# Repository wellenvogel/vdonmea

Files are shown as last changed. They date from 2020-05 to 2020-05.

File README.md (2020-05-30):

NMEA 0183 für VDO Windmesser
============================

Basierend auf einem Beitrag im [Segeln Forum](https://www.segeln-forum.de/board194-boot-technik/board35-elektrik-und-elektronik/board195-open-boat-projects-org/75527-reparaturhilfe-f%C3%BCr-vdo-windmessgeber/)
habe ich mit einem Arduino Nano und 8 Widerständen einen einfachen NMEA Adapter gebaut, der die Windrichtungsdaten und die Wind-Geschwindigkeit in einen MWV Datensatz übersetzt.
Der Arduino code enhtält einen einfachen Programmier-Mode um einen Abgleich auf die vorhandene Hardware zu machen.
Es müssen die Anschlüsse:
Farbe    |    Bedeutung
---------|--------------
grau     | Referenz-Spannung
weiss    | Geschwindigkeits-Puls
gelb     | "sinus"
grün     | "cosinus"
blau     | Masse

verbunden werden. 

Die Spannungswerte der 3 analogen Signale (grau,gelb,grün) werden mit Spannungsteilern auf auf einen Bereich von 0...ca. 3V umgesetzt, um sicher im Arbeitsbereich der A/D Wandler zu bleiben. Grau wird dabei als Referenz genutzt, damit ist die Versorgungsspannung des Arduino unkritisch.

Die Werte der Widerstände können ggf. im Sketch angepasst werden.

Wichtig ist es, vor der Nutzung eine Kalibrierung vorzunehmen - dazu nach den upload des sketch mit der seriellen Konsole verbinden (Standard: 19200 baud) und durch Eingabe von __xxprog__ in den Programmiermodus schalten.
Danach __minmax__ zum Start des Abgleichs der Minimal- und Maximalwerte angeben. Jetzt die Windfahne mehrfach langsam drehen bis sich die fortlaufend angezeigten Min- und Max-Werte nicht mehr ändern.
Jetzt die Fahne auf 0° stellen und mit dem Befehl __zero__ den 0-Offset einstellen.

Danach __save__ zum Speichern der Werte im Eeprom und __cancel__ zum Verlassen des Programmiermodus.

Es können noch weitere Werte eingestellt werden:

Kommando      |   Wert
--------------|---------
__interval__  | Aussende-Intervall in ms
__knotsperhz__| Knoten pro Hertz zum Anpassen der Geschwindigkeitsanzeige
__minpulse__  | minimale Zahle der Windimpulse, wenn in einem Intervall weniger Impulse vorhanden sind, wird über mehrere Intervalle gemittelt
__averagefactor__| Factor für eine Mittelwertbildung des Winkels (<1)
__talker__ | die genutzte talker id für den NMEA output

Im Programmier-Modus kann über __help__ eine Hilfe ausgegeben werden.

Falls eine "richtige" NMEA0183 Verbindung aufgebaut werden soll, müssen an den Arduino noch Pegelwandler angeschlossen werden (für die serielle Schnittstelle). Ausserdem benötigt er eine Stromversorgung.
Wenn aber ohnehin ein Anschluss per USB erfolgen soll (z.B. an einen Raspberry Pi) kann das direkt über die USB Schnittstelle des Arduino erfolgen.

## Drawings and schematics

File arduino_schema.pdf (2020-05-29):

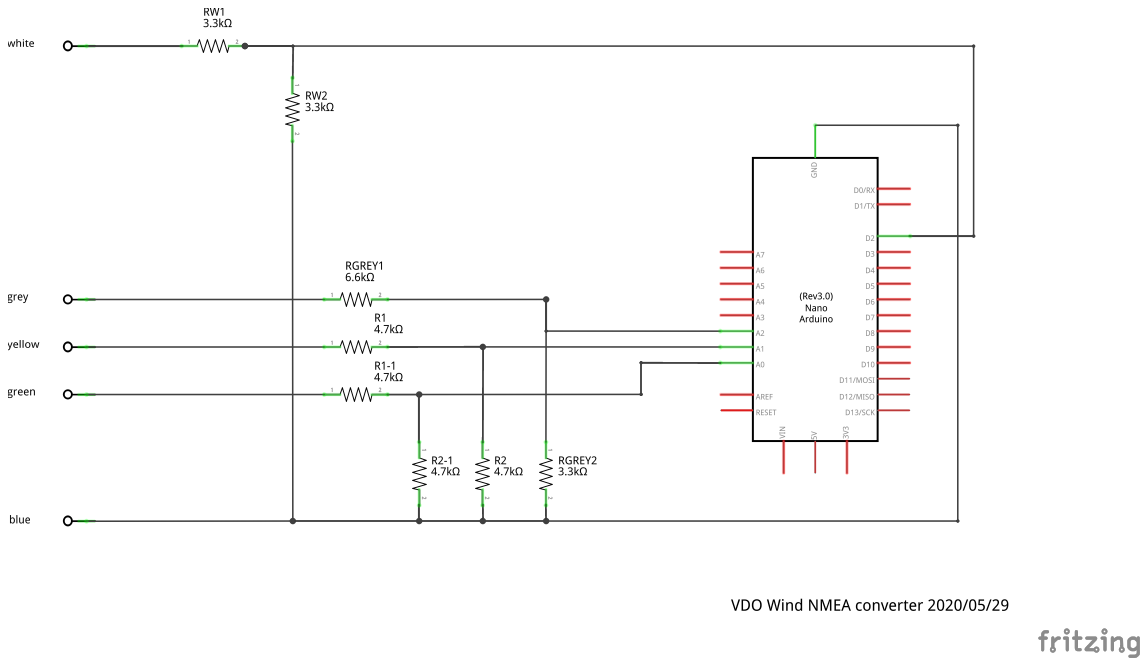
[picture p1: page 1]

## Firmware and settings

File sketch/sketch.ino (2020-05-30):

/**
 * sketch to read the wind data from a VDO
 * (C) Andreas Vogel, www.wellenvogel.de
 * License: MIT
 */
#include "Settings.h"
#define FH(x) (const __FlashStringHelper *)(x)
#define PM(n,value) static const PROGMEM char n[]=value


/*#define DEBUG*/
#define IPIN 2
//pins - grey: vref (~8V), green,yellow: direction
#define GREY_PIN A2
#define YELLOW_PIN A1
#define GREEN_PIN  A0
//NMEA output speed
#define SPEED 19200


//resistors used to divide the input voltage
//we assume similar ones for green and yellow
//the division should consider a low power on the arduino
//so in this set up input 6v will give us 3V at the arduino pins
#define R1 4.7
#define R2 4.7

//grey has different resistors to bringe the voltage more down
//with this set up we lower it to 1/3 - app. 2.75V for our voltage
#define RGREY1 6.6
#define RGREY2 3.3

//the measured reference voltage (grey line) - this is used as the reference for our voltages
#define VREF 8.23
/**
 * computation of angles
 * we start with some min/max values - but the will adapt
 * yellow is sin, green is cos
 * from the voltages we compute an angle and afterwards we average
 */



//values for min max when going to prog
#define PROG_MAX 3.1
#define PROG_MIN 3.0

const char DELIMITER[] = " ";
volatile unsigned long icount;
unsigned long lastCount;
unsigned long ts;
unsigned long lastOutput;
unsigned long lastInput;
char nmeabuf[100];

class TimeCount{
  public:
  unsigned long ts;
  unsigned long count;
  TimeCount(unsigned long count, unsigned long ts){
    this->count=0;
    this->ts=ts;
  }
  TimeCount(){
    count=0;
    ts=0;
  }
};

//how many counters we store
#define MAXCOUNT 10
TimeCount counterValues[MAXCOUNT];
int currentCounterValue;
int maxCounterValue;

#define MAXLINE 100
char receive[MAXLINE+1];
int receivedints=0;

void isr(){
  icount++;
}

#define ANALOG_RESOLUTION_BITS 10

float analogResolution = 1 << ANALOG_RESOLUTION_BITS;
float factor=(R1+R2)/R2/analogResolution;
float factorGrey=(RGREY1+RGREY2)/RGREY2/analogResolution;

float currentAngle;
//ignore voltages lower then this
#define MIN_MEASURE 0.5

//balance for averageing between cos and sin
//this is the weight if the value is at 0, if the value ist at 1 the weight is 1
//this honors that values around 0 are more precise that at 1
#define AVMAX 10

//the amplitude of sin/cos
float amp=1;

#define PROG_DELAY      5000
#define PROG_INTERVAL   1000
//programming mode
bool progMode;
bool progOutput;
bool minMaxMode;


Settings settings;



float hzToKn(float hz){
  return hz*settings.currentValues.hztokn;
}




int toHex(int c){
  c=c & 0xf;
  if (c <= 9) return '0'+c;
  else return 'A'+c-10;
}

const char * formatNmea(float windKn,float angle){
  char speeds[10];
  char angles[10];
  dtostrf(windKn,1,1,speeds);
  dtostrf(angle,1,1,angles);
  sprintf(nmeabuf,"$%c%cMWV,%s,R,%s,N,A",
    settings.currentValues.talker[0],
    settings.currentValues.talker[1],
    angles,speeds);
  int crc=0;
  for (int i=1;i<strlen(nmeabuf);i++){
    crc = crc ^ nmeabuf[i];
  }
  sprintf(nmeabuf+strlen(nmeabuf),"*%c%c",toHex(crc>>4),toHex(crc));
  return nmeabuf;
}


void computeAmplitude(){
  amp=(settings.currentValues.maxValue-settings.currentValues.minValue)/2;
}


float handleMinMax(float v){
  bool hasChanged=false;
  if (v > settings.currentValues.maxValue){
    if (! minMaxMode ){
      v=settings.currentValues.maxValue;
    }
    else{
      settings.currentValues.maxValue=v;
      hasChanged=true;
    }
  }
  if (v < settings.currentValues.minValue){
    if (! minMaxMode || v < MIN_MEASURE){
      v=settings.currentValues.minValue;
    }
    else{
      settings.currentValues.minValue=v;
      hasChanged=true;
    }
  }
  if (hasChanged){
    computeAmplitude();
  }
  return v;
}


float getWeight(float v){
  if (v < 0) v = -v;
  v= (1-v) * (AVMAX-1) +1;
  return v;
}
#define MAXVAL 0.99999
float computeAngle(bool doAverage=true){
  float grey=(float)analogRead(GREY_PIN)*factorGrey;
  float windAngle=0;
  float scale=1.0;
  if (grey < 0.01){
    Serial.print("grey to small");
    Serial.println();
    return 0.0;
  }
  else{
    scale=VREF/grey;
  }
  int green=analogRead(GREEN_PIN);
  float vgreen=factor*green*scale;
  int yellow=analogRead(YELLOW_PIN);
  float vyellow=factor*yellow*scale;

  float vyellowC=handleMinMax(vyellow);
  float vgreenC=handleMinMax(vgreen);
  float vgscaled=(vgreenC-settings.currentValues.minValue)/amp-1;
  if (vgscaled >= 1) vgscaled=MAXVAL;
  if (vgscaled <= -1) vgscaled=-MAXVAL;
  float vyscaled=(vyellowC-settings.currentValues.minValue)/amp-1;
  if (vyscaled >= 1) vyscaled=MAXVAL;
  if (vyscaled <= -1) vyscaled=-MAXVAL;

  float weighty=getWeight(vyscaled);
  float weightg=getWeight(vgscaled);
  //now the quadrants 
  //asin from -90...90
  //acos from 0...180
  float wsin=180/PI*asin(vyscaled);
  float wcos=180/PI*acos(vgscaled);
  //1. 0...90 wsin ok, wcos ok (both 0...90)
  if (vyscaled >=0 && vgscaled >=0){
    if (wcos >= 90) wcos=180-wcos;
  } else
  //2. 90...180 wcos ok, wsin correct 
  if (vyscaled >=0 && vgscaled <=0) {
    if (wsin < 90) wsin=180.0-wsin;
  } else
  //3. -180...-90
  if (vyscaled < 0 && vgscaled < 0){
     wsin=-180-wsin;
     wcos=-wcos;
  }else
  //4. -90...0 wsin ok, wcos correct
  if (vyscaled <0 && vgscaled >=0){
    wcos=-wcos;
  }
  float diffraw=wsin-wcos;
  if ((wsin < -170 || wsin > 170) && (wcos < -170 || wcos > 170) && (diffraw < -180 || diffraw > 180)){
    //sin is the better one in this area
    wcos=-wcos;
  }
  float wfinal=(weighty *wsin+ weightg*wcos)/(weighty+weightg) + settings.currentValues.offset;
  float delta=wfinal-currentAngle;
  if ((wfinal > 170 || wfinal < -170) && (currentAngle > 170 || currentAngle < -170) && (delta > 180 || delta < -180) ){
    //special handling around +/-180
    currentAngle=-currentAngle;
  }
  currentAngle=currentAngle + settings.currentValues.maf*(wfinal-currentAngle);
  if (settings.currentValues.showText || progMode){
    Serial.print(grey);
    Serial.print(", scale=");
    Serial.print(scale);
    Serial.print(", yellow=");
    Serial.print(vyellow);
    Serial.print(", green=");
    Serial.print(vgreen);
    Serial.print(" ,");
    Serial.print(green);
    Serial.print(", min=");
    Serial.print(settings.currentValues.minValue);
    Serial.print(", max=");
    Serial.print(settings.currentValues.maxValue);
    Serial.print(", amp=");
    Serial.print(amp);
    Serial.print(", asin=");
    Serial.print(wsin);
    Serial.print(", acos=");
    Serial.print(wcos);
    Serial.print(", wfinal=");
    Serial.print(wfinal);
    Serial.print(", angle=");
    Serial.print(currentAngle);
    Serial.println();
  }
  float rt=doAverage?currentAngle:wfinal;
  if (rt > 180) rt=-360+rt;
  if (rt < -180) rt=360+rt;
  return rt;
}

static const PROGMEM char HELP[]="Help:\n"
  "XXPROG             : start prog mode\n"
  "    --- other only in prog mode ---\n"
  "CANCEL             : leave prog mode\n"
  "RELOAD             : reload settings\n"
  "RESET              : load default settings\n"
  "SAVE               : save settings\n"
  "MINMAX             : start/stop min/max detection, slowly rotate vane\n"
  "INTERVAL      ms   : set ouput interval\n"
  "KNOTSPERHZ    fact : set the factor from hz to knots\n"
  "MINPULSE      val  : average to get at least that many pulses (max 10 periods back)\n"
  "AVERAGEFACTOR fact : set the moving average factor for angle\n"
  "SHOWTEXT      0|1  : show debug output in normal mode\n"
  "TALKER        XY   : set talker ID\n"
  "OUTPUT             : toggle output in prog mode\n";

void handleSerialLine(const char *receivedData) {
  char * tok = strtok(receivedData, DELIMITER);
  if (! tok) {
    if (!progMode) return;
    settings.printValues();
    return;
  }
  int num=0;
  if (strcasecmp(tok, "XXPROG") == 0) {
    progMode=true;
    minMaxMode=false;
    progOutput=false;
    Serial.println("PROG started");
    settings.printValues();
    return;
  }
  if (! progMode) return;
  if (strcasecmp(tok,"ZERO") == 0){
      Serial.print("set as offset ");
      float current=computeAngle(false);
      settings.currentValues.offset+=-current;
  }
  if (strcasecmp(tok,"CANCEL") == 0){
    if (settings.isDirty()){
      Serial.println("settings changed, use RELOAD before");
    }
    else{
      progMode=false;
      minMaxMode=false;
    }
  }
  if (strcasecmp(tok,"MINMAX") == 0){
    Serial.print("MINMAX MODE=");
    minMaxMode=!minMaxMode;
    Serial.println(minMaxMode);
    if (minMaxMode){
      settings.currentValues.minValue=PROG_MIN;
      settings.currentValues.maxValue=PROG_MAX;    
    }
  }
  if (strcasecmp(tok,"RELOAD") == 0){
    Serial.println("RELOAD");
    minMaxMode=false;
    settings.reload();
    computeAmplitude();    
  }
  if (strcasecmp(tok,"RESET") == 0){
    Serial.println("RESET");
    
    settings.reset(false);
    computeAmplitude();    
  }
  if (strcasecmp(tok, "SAVE") == 0) {
    Serial.println("SAVE");
    minMaxMode=false;
    settings.write();
  }
  if (strcasecmp(tok,"INTERVAL") == 0 ){
    char *val=strtok(NULL, DELIMITER);
    if (val){
      settings.currentValues.interval=atoi(val);
      Serial.println("INTERVAL");
    }
  }
  if (strcasecmp(tok,"KNOTSPERHZ") == 0 ){
    char *val=strtok(NULL, DELIMITER);
    if (val){
      settings.currentValues.hztokn=atof(val);
      Serial.println("KNOTSPERHZ");
    }
  }
  if (strcasecmp(tok,"MINPULSE") == 0 ){
    char *val=strtok(NULL, DELIMITER);
    if (val){
      settings.currentValues.minCount=atoi(val);
      Serial.println("MINPULSE");
    }
  }
  if (strcasecmp(tok,"AVERAGEFACTOR") == 0 ){
    char *val=strtok(NULL, DELIMITER);
    if (val){
      float fac=atof(val);
      if (fac < 0.1 || fac > 1){
        Serial.println("FACTOR out of range 0.1...1");
      }
      else{
        settings.currentValues.maf=fac;
        Serial.println("AVERAGEFACTOR");
      }
    }
  }
  if (strcasecmp(tok,"SHOWTEXT") == 0 ){
    char *val=strtok(NULL, DELIMITER);
    if (val){
      settings.currentValues.showText=atoi(val) != 0;
      Serial.println("SHOWTEXT");
    }
  }
  if (strcasecmp(tok,"TALKER") == 0 ){
    char *val=strtok(NULL, DELIMITER);
    if (val && strlen(val) >=2){
      settings.currentValues.talker[0]=*val &0x5f;
      settings.currentValues.talker[1]=*(val+1) & 0x5f;
      Serial.println("TALKER");
    }
  }
  if (strcasecmp(tok,"OUTPUT") == 0){
    progOutput=!progOutput;
    Serial.print("OUTPUT=");
    Serial.println(progOutput);
  }
  if (strcasecmp(tok,"HELP") == 0 || strcasecmp(tok,"?") == 0){
    Serial.print(FH(HELP));
  }
  settings.printValues();
}

void addCount(unsigned long count, unsigned long ts){
#ifdef DEBUG
    Serial.print("ADDC c=");
    Serial.print(count);
    Serial.print(", ts=");
    Serial.println(ts);
#endif    
    counterValues[currentCounterValue].count=count;
    counterValues[currentCounterValue].ts=ts;
    currentCounterValue++;
    if (currentCounterValue >= MAXCOUNT) currentCounterValue=0;
    if (currentCounterValue > maxCounterValue) maxCounterValue++;
}

/**
 * get a nicely averaged frequency
 * we would like to have a minimal amount of pulses
 * otherwise we go back in history and average over multiple periods
 */
float getAveragedHz(unsigned long minCount){
    if (maxCounterValue < 2) return 0.0;
    int numEntries=maxCounterValue;
    int i=currentCounterValue-1;
    if (i<0) i=MAXCOUNT-1;
    unsigned long lastCount=counterValues[i].count;
    unsigned long lastTs=counterValues[i].ts;    
    int usedIndex=i;
    while (numEntries >0){        
        i--;
        if (i<0) i=MAXCOUNT-1;
        numEntries--;
        usedIndex=i;
        unsigned long diff=lastCount - counterValues[usedIndex].count;        
#ifdef DEBUG
        Serial.print("AVHZ diff=");
        Serial.print(diff);
        Serial.print(", idx=");
        Serial.println(i);
#endif        
        if (diff >= minCount) break;
    }
    long counterDiff=lastCount-counterValues[usedIndex].count;
    long timeDiff=lastTs-counterValues[usedIndex].ts;
    if (counterDiff <0 || timeDiff <= 0) return 0.0;
    return (float)counterDiff*1000.0/(float)timeDiff; 
}


void setup() {
  icount=0;
  lastCount=0;
  attachInterrupt(digitalPinToInterrupt(IPIN),isr,RISING);
  Serial.begin(SPEED);
  ts=millis();
  lastOutput=ts;
  lastInput=ts;
  progMode=false;
  minMaxMode=false;
  progOutput=false;
  settings.loadValues();
  amp=(settings.currentValues.maxValue-settings.currentValues.minValue)/2;
  currentCounterValue=0;
  maxCounterValue=0;
  addCount(lastCount,ts);
  currentAngle=0;
}
void loop() {
  unsigned long currentTime=millis();
  if (currentTime <= ts){
    //overflow, skip this
    ts=currentTime;
    lastOutput=ts;
    return;
  }
  while (Serial.available() > 0) {
    int c = Serial.read();
    if (c < 0) break;
    if (c < 0x20 || receivedints >= MAXLINE){
      lastInput=ts;
      receive[receivedints]=0;
      handleSerialLine(receive);
      receivedints=0;
      break;
    }
    receive[receivedints]=c;
    receivedints++;
  }
  if (! progMode){
    if ((currentTime-lastOutput) < settings.currentValues.interval){
      delay(2);
      return;
    }
  }
  else{
    if ((currentTime-lastInput) < PROG_DELAY){
      delay(2);
      return;
    }
    if ((currentTime - lastOutput) < PROG_INTERVAL || ! (progOutput || minMaxMode)){
      delay(2);
      return;
    }
  }
  lastOutput=currentTime;
  unsigned long currentCount=icount;
  if (currentCount < lastCount){
    //overflow - skip
    lastCount=currentCount;
    return;
  }
  addCount(currentCount,currentTime);
  unsigned long diff=currentTime-ts;
  ts=currentTime;
  lastCount=currentCount;
  float freq=getAveragedHz(settings.currentValues.minCount);
  float windKn=hzToKn(freq);
  if (settings.currentValues.showText || progMode){
    if (progMode) Serial.print("[PROG] ");
    Serial.print("tdiff=");
    Serial.print(diff);
    Serial.print(", count=");
    Serial.print(currentCount);
    Serial.print(", freq=");
    Serial.print(freq);
    Serial.print(", kn=");
    Serial.print(windKn);
    Serial.print(", greyBase=");    
  }
  float wfinal=computeAngle();
  Serial.print(formatNmea(windKn,wfinal));
  Serial.println();
  
}

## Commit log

2020-05-27 1st working version
    [Angles.ods]
2020-05-29 added readme, schema, handle average correctly
    [arduino.fzz]
2020-05-30 handle values around 180/-180 more intelligent
    [Angles.ods]
